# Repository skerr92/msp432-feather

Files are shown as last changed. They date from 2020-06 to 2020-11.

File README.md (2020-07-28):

# msp432-feather

Welcome to the public repository for my MSP432P401R feather board design. There are just a few things that should be considered when working with this design. 

<image src="images/Screen Shot 2020-07-28 at 7.55.07 PM.png">
  
# Update (07-28-2020): Fixed issues with bad footprint for FT232RL chip

There was a connection and foodprint issue with the FT232RL chip which need to be replaced. That is reflected in the current board and schematic files.

In addition to this, 4 JTAG header pins are also added to allow programming from a MSP432P401R development board.

# Update (07-16-2020)

The schematic and board files were fixed related to the floating TEST pin on the FT232RL IC.

# Update (07-11-2020): If you choose to manufacture the current board uploaded read this first (fixed):

The old schematic is working to be updated following an issue with the FT232RL USB to UART chip. This is easy to overcome when assembling the current board, simply bridge pins 25 and 26 on the board. This ensures that pin 25 (TEST) is tied to pin 26 (GND). According to the FT232R datasheet, the chip won't be recognized because the test pin is floating. This will be corrected in the next revision.

# Get started today

You can get started by ordering the board from OshPark --> <a href="https://oshpark.com/shared_projects/jjmrRj4x">MSP432 Boards on OshPark</a>

# 1

The design is open for revision. If you have experience with PCB design and would like to contribue, I encourage you to do so! Simply create a fork of the repository and you're good to go!

If you are new to PCB design and want to play around with the files, you can do that to! Just download autodesk eagle through autodesk fusion and you can get started.

# 2

The BOM and board files are included for convenience if you so chose to build out this board. I am in the midst of testing the current design so I haven't worked out all the flaws that might be associate with this PCB. 

I should be done with the first board by the end of August, and I'll update the board files, schematic, and the lot as necessary.

# final thoughts

This board is the second board I have been working on and adding the the open source community. With hard work, I hope that this board can be successfully submitted the the Open Hardware Association as a means to help others who want to develop with the MSP432, can do so with the additional support of the Adafruit feather wings and other add-on boards.

If you have any questions, you can open up an issue in the <a href="https://github.com/skerr92/msp432-feather/issues">Issues</a> tab of this repository!

Please check the <a href="https://github.com/skerr92/msp432-feather/tree/master/technical%20documentation">Technical Documentation</a> for additional resources for working with the MSP432P4xxx microcontroller.

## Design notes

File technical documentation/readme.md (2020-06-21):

# Getting started

Please see the data sheet for information on the feather board and associated pin out.

In addition to the technical document, please refer to the MSP432P401R bootloader uploading instructions from Texas Instruments that can be found below.

<a href="https://www.ti.com/lit/ug/slau622j/slau622j.pdf?ts=1592760815341">MSP432 bootloader instructions</a>

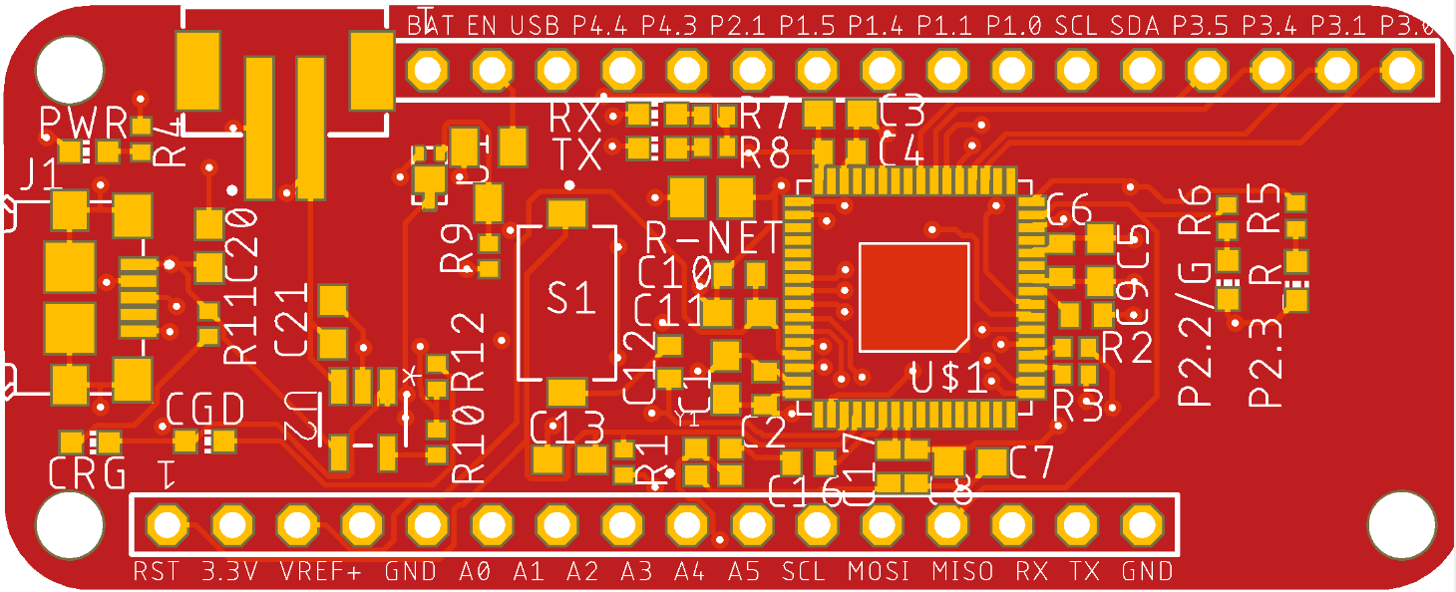
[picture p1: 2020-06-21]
images/Screen Shot 2020-06-17 at 4.03.39 PM.png

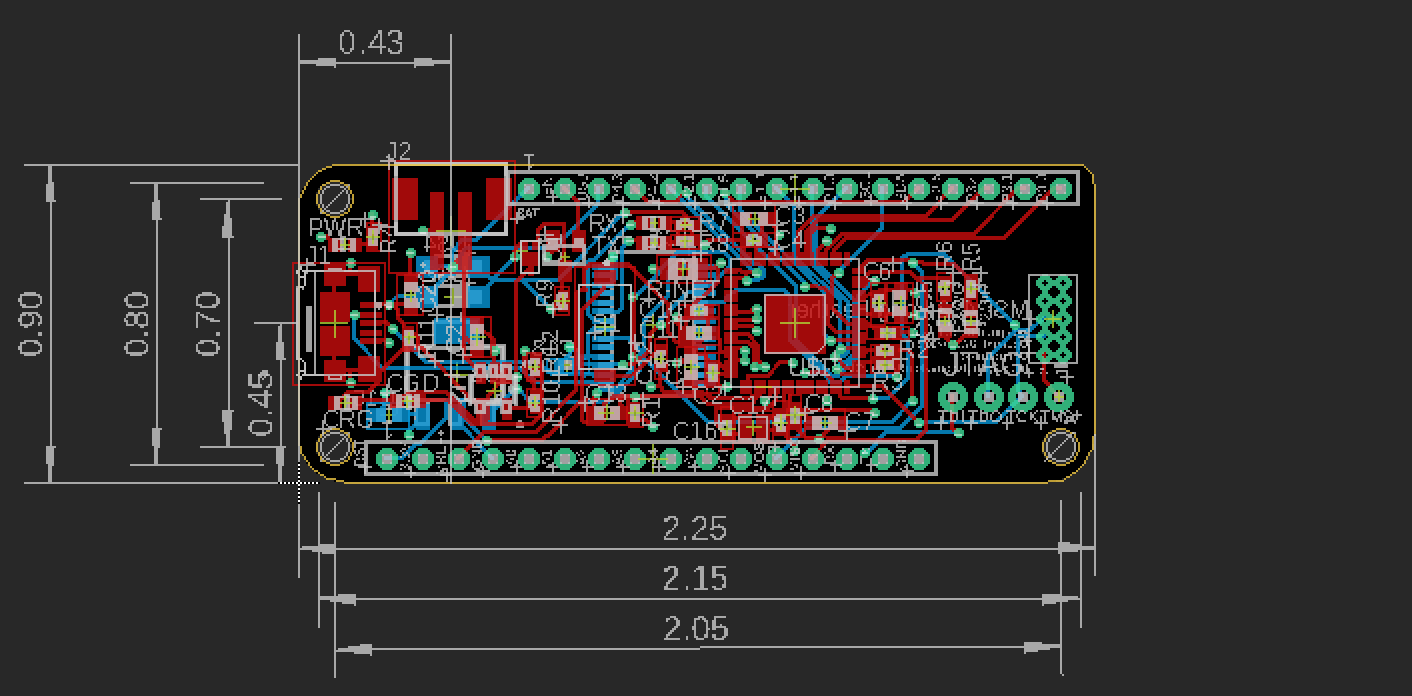
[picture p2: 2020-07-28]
images/Screen Shot 2020-07-28 at 7.55.07 PM.png

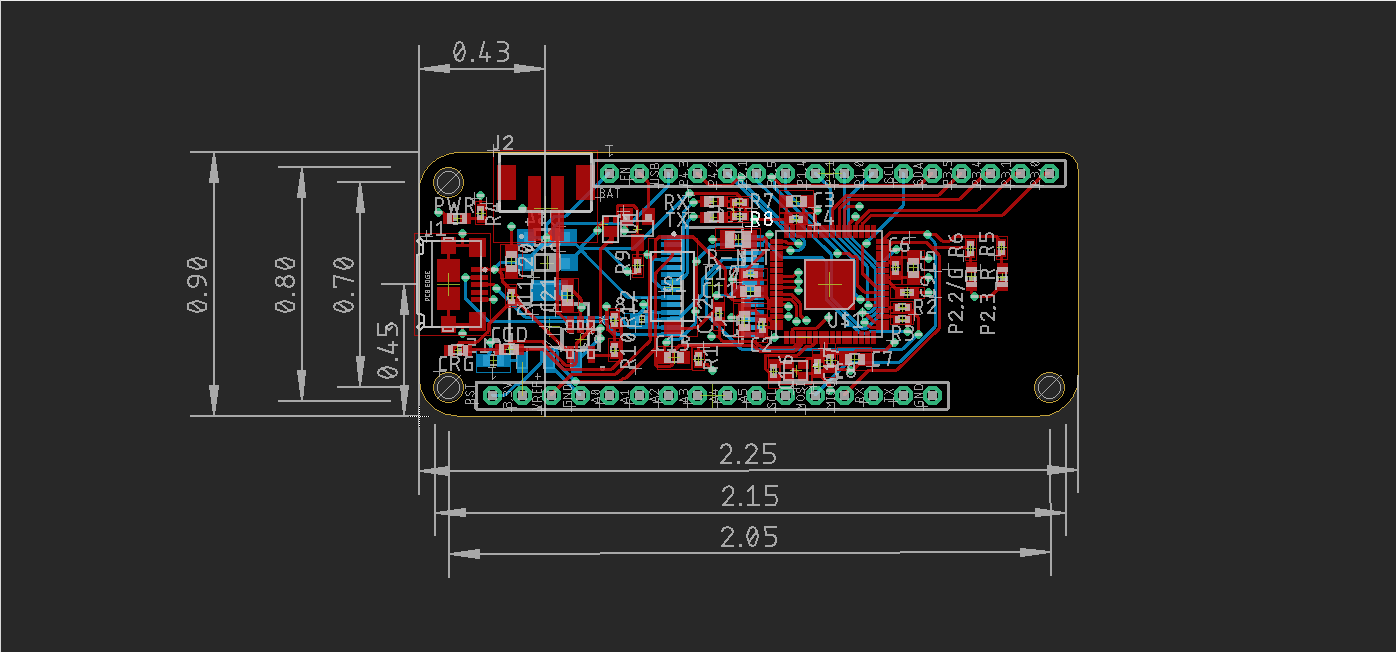
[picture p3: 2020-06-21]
images/Screen Shot 2020-06-21 at 1.09.43 PM.png

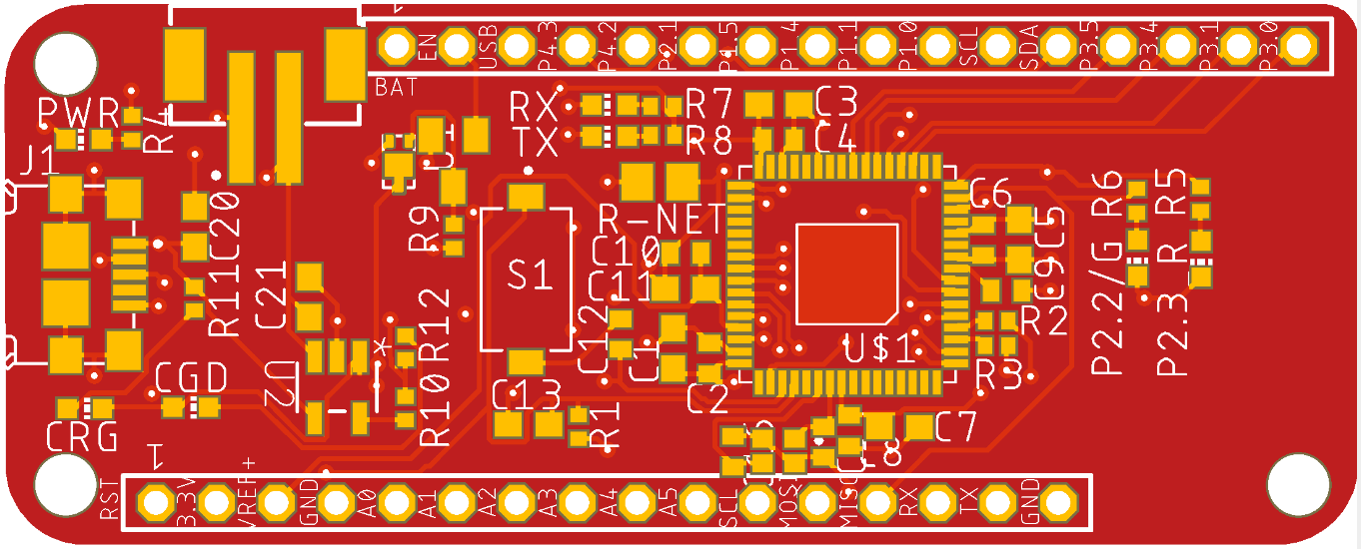
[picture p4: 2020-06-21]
images/Screen Shot 2020-06-17 at 5.07.13 PM.png

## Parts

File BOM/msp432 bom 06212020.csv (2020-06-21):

Index | Quantity | Part Number | Manufacturer Part Number | Description | Customer Reference | Available | Backorder | Unit Price | Extended Price USD
1 | 1 | 768-1007-1-ND | FT232RL-REEL | IC USB FS SERIAL UART 28-SSOP |  | 1 | 0 | 4.50000 | 4.50
2 | 1 | 455-1734-1-ND | B2B-PH-SM4-TB(LF)(SN) | CONN HEADER SMD 2POS 2MM |  | 1 | 0 | 0.55000 | 0.55
3 | 1 | 296-45565-1-ND | MSP432P401RIRGCR | IC MCU 32BIT 256KB FLASH 64VQFN |  | 1 | 0 | 6.66000 | 6.66
4 | 2 | MBR0520LT1GOSCT-ND | MBR0520LT1G | DIODE SCHOTTKY 20V 500MA SOD123 |  | 2 | 0 | 0.29000 | 0.58
5 | 1 | DMG3415UFY4Q-7DICT-ND | DMG3415UFY4Q-7 | MOSFET P-CH 16V 2.5A X2-DFN2015 |  | 1 | 0 | 0.51000 | 0.51
6 | 1 | BSS138CT-ND | BSS138 | MOSFET N-CH 50V 220MA SOT-23 |  | 1 | 0 | 0.26000 | 0.26
7 | 1 | MIC5239-3.3YS-CT-ND | MIC5239-3.3YS-TR | IC REG LINEAR 3.3V 500MA SOT223 |  | 1 | 0 | 2.66000 | 2.66
8 | 2 | 511-1494-1-ND | TCM0J106M8R | CAP TANT 10UF 20% 6.3V 0603 |  | 2 | 0 | 0.62000 | 1.24
9 | 1 | 445-8022-1-ND | C1005X5R1A335M050BC | CAP CER 3.3UF 10V X5R 0402 |  | 1 | 0 | 0.49000 | 0.49
10 | 2 | 399-7775-1-ND | C0402C220K5GACTU | CAP CER 22PF 50V C0G/NP0 0402 |  | 2 | 0 | 0.10000 | 0.20
11 | 10 | 1276-1004-1-ND | CL05F104ZO5NNNC | CAP CER 0.1UF 16V Y5V 0402 |  | 10 | 0 | 0.02000 | 0.20
12 | 1 | 399-9948-1-ND | C0402C112J5GAC7867 | CAP CER 1100PF 50V C0G/NP0 0402 |  | 1 | 0 | 0.54000 | 0.54
13 | 1 | 490-1316-1-ND | GRM155R71A473KA01D | CAP CER 0.047UF 10V X7R 0402 |  | 1 | 0 | 0.10000 | 0.10
14 | 5 | 718-2358-1-ND | TMCJ0J475MTRF | CAP TANT 4.7UF 20% 6.3V 0603 |  | 5 | 0 | 0.39000 | 1.95
15 | 2 | 311-220LRCT-ND | RC0402FR-07220RL | RES SMD 220 OHM 1% 1/16W 0402 |  | 2 | 0 | 0.10000 | 0.20
16 | 1 | RMCF0805ZT0R00CT-ND | RMCF0805ZT0R00 | RES 0 OHM JUMPER 1/8W 0805 |  | 1 | 0 | 0.10000 | 0.10
17 | 3 | A130045CT-ND | CRGCQ0402J330R | CRGCQ 0402 330R 5% |  | 3 | 0 | 0.10000 | 0.30
18 | 2 | A130046CT-ND | CRGCQ0402J470R | CRGCQ 0402 470R 5% |  | 2 | 0 | 0.10000 | 0.20
19 | 2 | P1.0KJCT-ND | ERJ-2GEJ102X | RES SMD 1K OHM 5% 1/10W 0402 |  | 2 | 0 | 0.10000 | 0.20
20 | 1 | A130375CT-ND | CRGP0402F47K | CRGP 0402 47K 1% |  | 1 | 0 | 0.10000 | 0.10
21 | 1 | 311-100KLRCT-ND | RC0402FR-07100KL | RES SMD 100K OHM 1% 1/16W 0402 |  | 1 | 0 | 0.10000 | 0.10
22 | 1 | P2.20KLCT-ND | ERJ-2RKF2201X | RES SMD 2.2K OHM 1% 1/10W 0402 |  | 1 | 0 | 0.10000 | 0.10
23 | 3 | 732-4966-1-ND | 150060BS75000 | LED BLUE CLEAR 0603 SMD |  | 3 | 0 | 0.16000 | 0.48
24 | 2 | 350-2035-1-ND | 5988070107F | LED GREEN CLEAR 0603 SMD |  | 2 | 0 | 0.42000 | 0.84
25 | 2 | 732-4978-1-ND | 150060RS75000 | LED RED CLEAR 0603 SMD |  | 2 | 0 | 0.14000 | 0.28
26 | 1 | XC2668CT-ND | ECS-480-10-37-JTN-TR | CRYSTAL 48MHZ 10PF SMD |  | 1 | 0 | 0.66000 | 0.66
27 | 1 | 609-5379-1-ND | 10118192-0002LF | CONN RCPT USB2.0 MICRO B SMD R/A |  | 1 | 0 | 0.46000 | 0.46

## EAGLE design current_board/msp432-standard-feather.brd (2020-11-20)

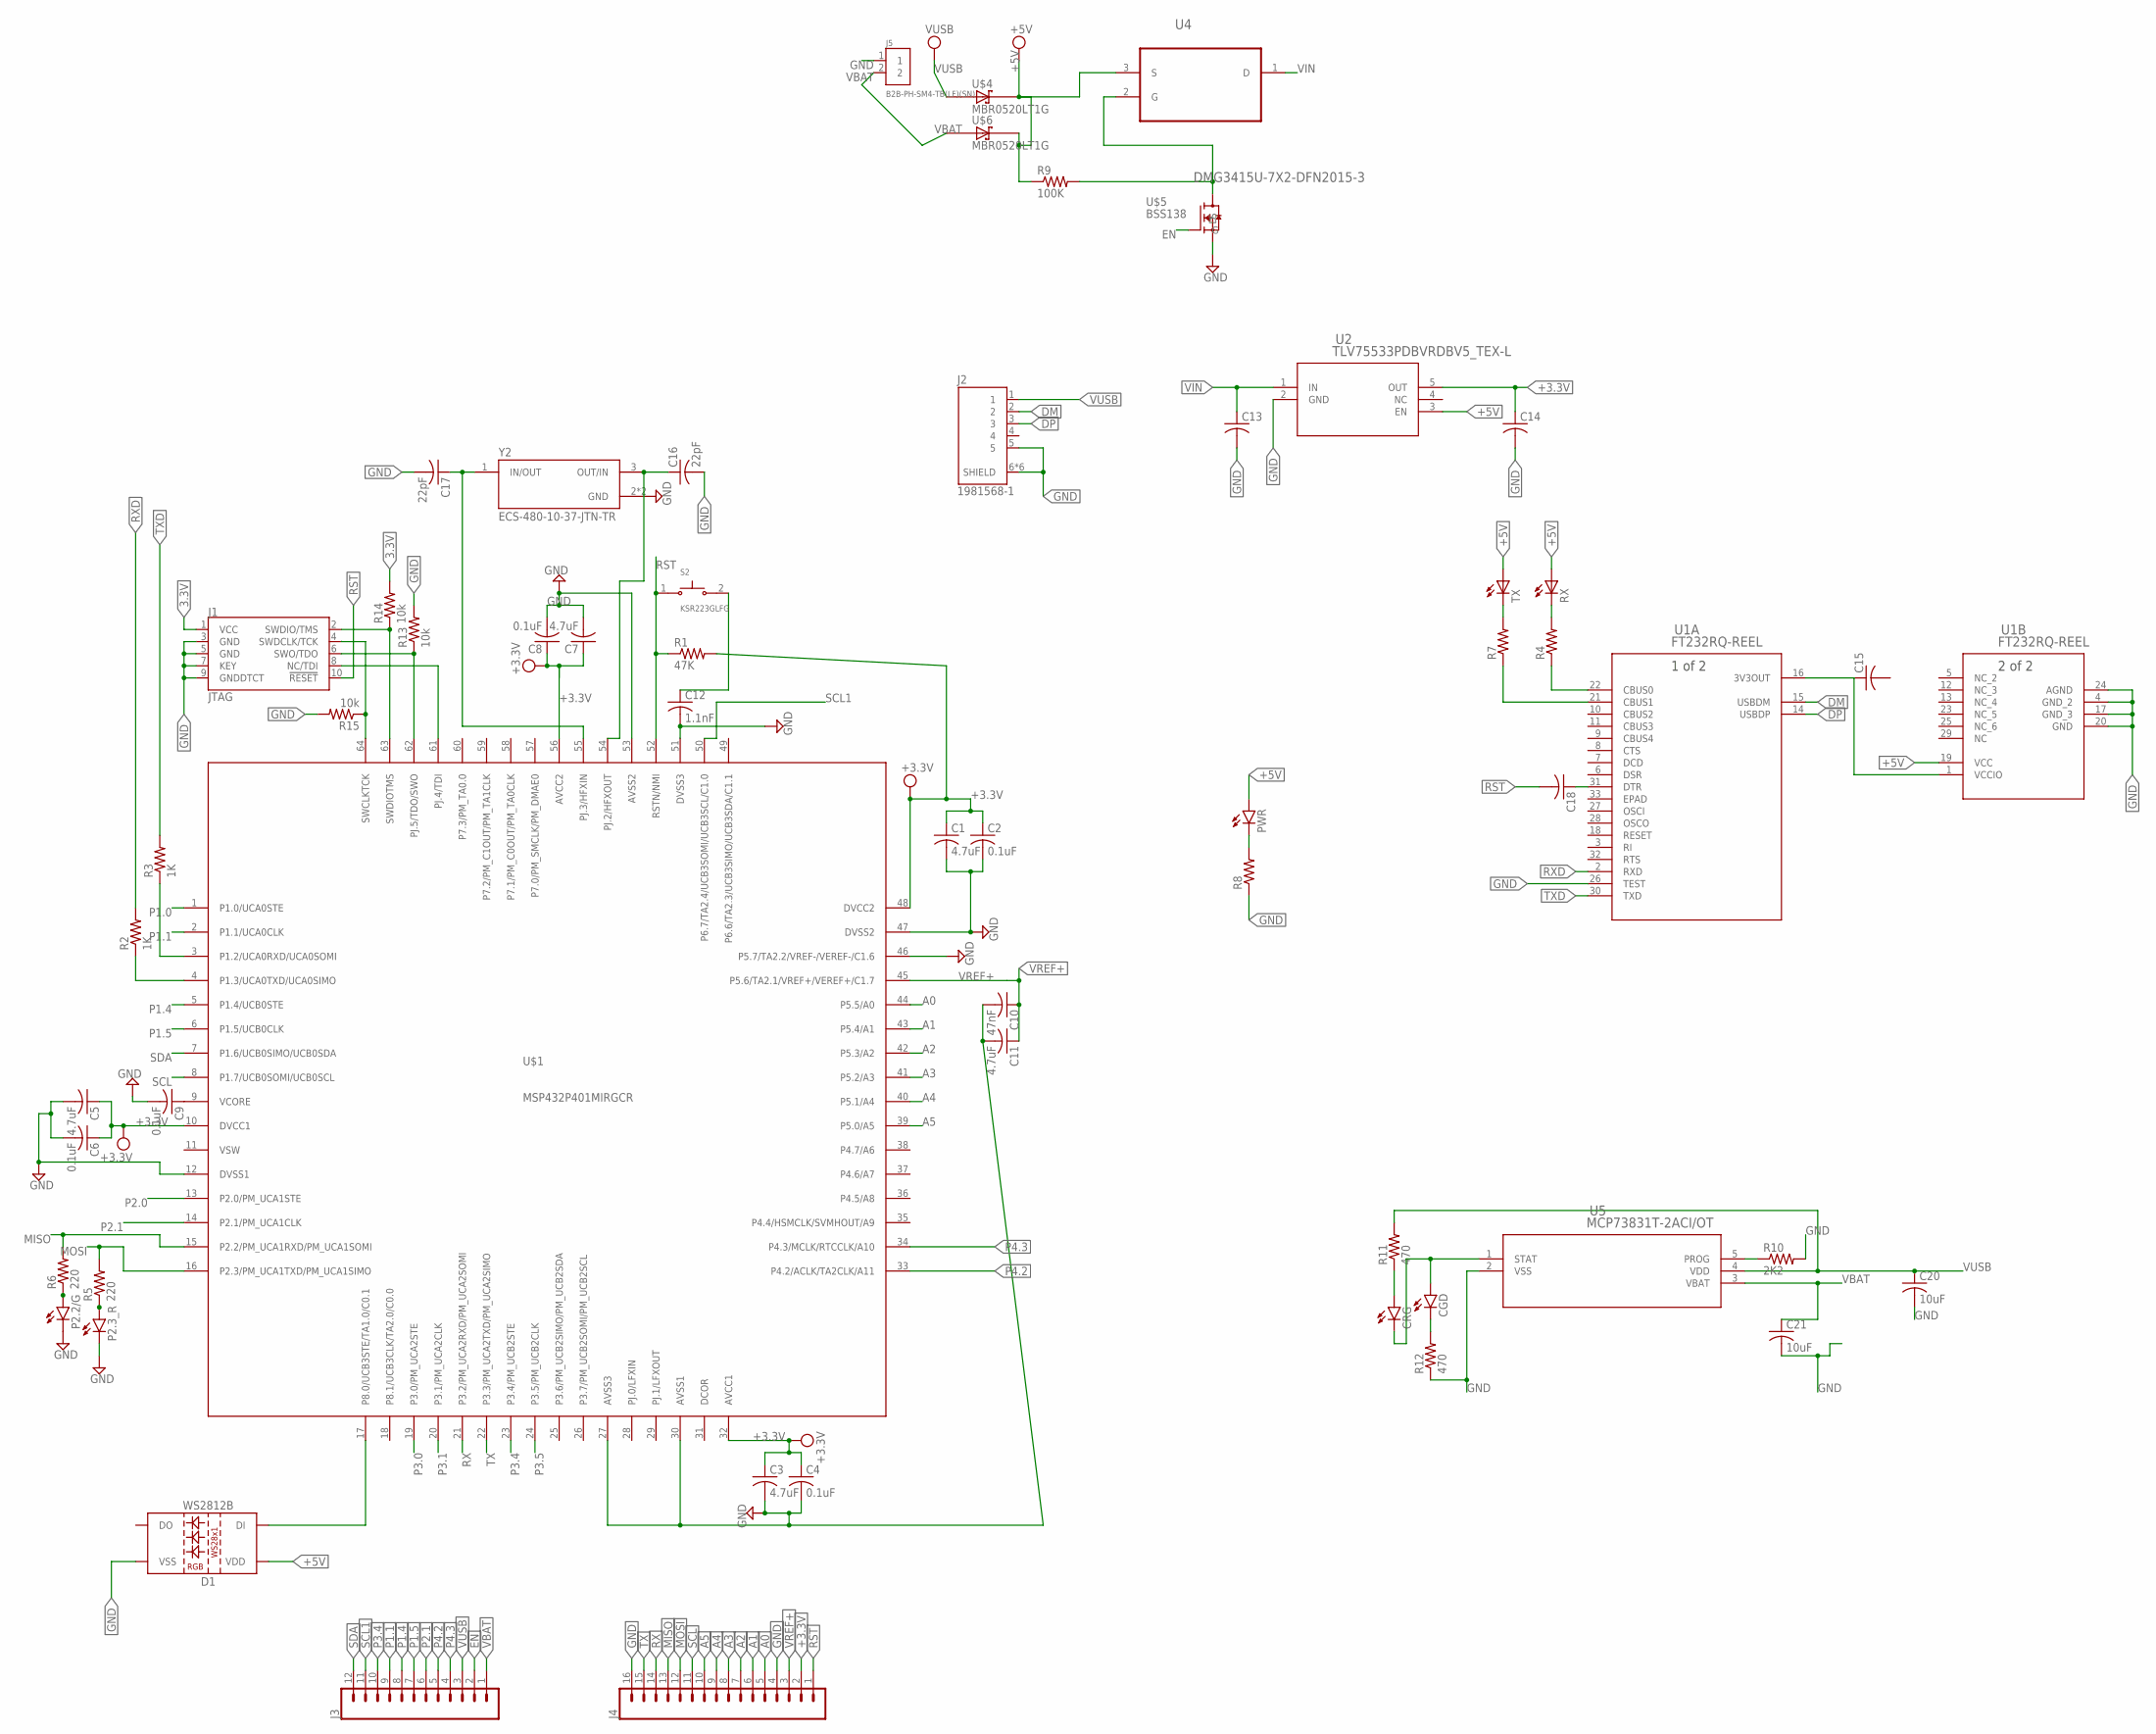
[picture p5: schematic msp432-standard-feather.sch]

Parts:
C1, C3, C5, C7, C11: 4.7uF; C0603
C2, C4, C6, C8, C9: 0.1uF; C0402
C10: 47nF; C0402
C12: 1.1nF; C0402
C13, C14, C15, C18: C-USC0402; C0402
C16, C17: 22pF; C0402
C20, C21: 10uF; C0603
CGD: LEDCHIP-LED0603; CHIP-LED0603
CRG: LEDCHIP-LED0603; CHIP-LED0603
D1: WS2812B
J1: JTAG; 2X5-SMD-1.27MM
J2: 1981568-1; TE_1981568-1
J3: CONN_12NO_SILK; 1X12_NO_SILK
J4: CONN_161X16_NO_SILK; 1X16_NO_SILK
J5: B2B-PH-SM4-TB(LF)(SN); JST_B2B-PH-SM4-TB(LF)(SN)
P2.2/G, P2.3_R: LEDCHIP-LED0603; CHIP-LED0603
PWR: LEDCHIP-LED0603; CHIP-LED0603
R1: 47K; R0402
R2, R3: 1K; R0402
R4, R7, R8: R-US_R0402; R0402
R5, R6: 220; R0402
R9: 100K; R0402
R10: 2K2; R0402
R11, R12: 470; R0402
R13, R14, R15: 10k; R0402
RX: LEDCHIP-LED0603; CHIP-LED0603
S2: KSR223GLFG; SW_KSR223GLFG
TX: LEDCHIP-LED0603; CHIP-LED0603
U1: FT232RQ-REEL; FT232RQ-REEL_FTD
U2: TLV75533PDBVRDBV5_TEX-L; DBV5_TEX-L
U4: DMG3415U-7X2-DFN2015-3; X2-DFN2015-3
U5: MCP73831T-2ACI/OT; SOT-23-5_MC
U$1: MSP432P401MIRGCR; MSP432_QFN_64
U$4, U$6: MBR0520LT1G; SOD3716X117(SOD-123)
U$5: BSS138
Y2: ECS-480-10-37-JTN-TR; XTAL_ECS-480-10-37-JTN-TR

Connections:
3.3V: J1.1 (VCC), R14.2
+3.3V: C1.1, C2.1, C3.1, C4.1, C5.1, C6.1, C7.1, C8.1, C14.1, J4.2, R1.2, U2.5 (OUT), U$1.10 (DVCC1), U$1.32 (AVCC1), U$1.48 (DVCC2), U$1.56 (AVCC2)
+5V: D1.1 (VDD), PWR.A, R9.1, RX.A, TX.A, U1.19 (VCC), U2.3 (EN), U4.3 (S), U$4.1 (C), U$6.1 (C)
A0: J4.5, U$1.44 (P5.5/A0)
A1: J4.6, U$1.43 (P5.4/A1)
A2: J4.7, U$1.42 (P5.3/A2)
A3: J4.8, U$1.41 (P5.2/A3)
A4: J4.9, U$1.40 (P5.1/A4)
A5: J4.10, U$1.39 (P5.0/A5)
DM: J2.2, U1.15 (USBDM)
DP: J2.3, U1.14 (USBDP)
EN: J3.2, U$5.G
GND: C1.2, C2.2, C3.2, C4.2, C5.2, C6.2, C7.2, C8.2, C9.2, C10.2, C11.2, C12.2, C13.2, C14.2, C16.2, C17.2, C20.2, C21.2, D1.3 (VSS), J1.3 (GND), J1.5 (GND), J1.7 (KEY), J1.9 (GNDDTCT), J2.5, J2.6 (SHIELD), J2.7 (SHIELD), J2.8 (SHIELD), J2.9 (SHIELD), J2.10 (SHIELD), J2.11 (SHIELD), J4.4, J4.16, J5.1, P2.2/G.C, P2.3_R.C, R8.1, R10.2, R12.1, R13.2, R15.2, U1.4 (GND_2), U1.17 (GND_3), U1.20 (GND), U1.24 (AGND), U1.26 (TEST), U2.2 (GND), U5.2 (VSS), U$1.12 (DVSS1), U$1.27 (AVSS3), U$1.30 (AVSS1), U$1.46 (P5.7/TA2.2/VREF-/VEREF-/C1.6), U$1.47 (DVSS2), U$1.51 (DVSS3), U$1.53 (AVSS2), U$5.S, Y2.2 (GND), Y2.4 (GND)
MISO: J4.13, R6.2, U$1.15 (P2.2/PM_UCA1RXD/PM_UCA1SOMI)
MOSI: J4.12, R5.2, U$1.16 (P2.3/PM_UCA1TXD/PM_UCA1SIMO)
unnamed: C9.1, U$1.9 (VCORE)
unnamed: R10.1, U5.5 (PROG)
unnamed: C15.1, U1.1 (VCCIO), U1.16 (3V3OUT)
unnamed: C18.1, U1.31 (DTR)
unnamed: R7.1, U1.21 (CBUS1)
unnamed: R4.1, U1.22 (CBUS0)
unnamed: R4.2, RX.C
unnamed: R7.2, TX.C
unnamed: J1.4 (SWDCLK/TCK), R15.1, U$1.64 (SWCLKTCK)
unnamed: C12.1, S2.2
unnamed: J1.2 (SWDIO/TMS), R14.1, U$1.63 (SWDIOTMS)
unnamed: PWR.C, R8.2
unnamed: P2.2/G.A, R6.1
unnamed: R2.1, U$1.4 (P1.3/UCA0TXD/UCA0SIMO)
unnamed: R3.1, U$1.3 (P1.2/UCA0RXD/UCA0SOMI)
unnamed: J1.6 (SWO/TDO), R13.1, U$1.62 (PJ.5/TDO/SWO)
unnamed: R9.2, U4.2 (G), U$5.D
unnamed: CGD.A, CRG.C, U5.1 (STAT)
unnamed: J1.8 (NC/TDI), U$1.61 (PJ.4/TDI)
unnamed: D1.4 (DI), U$1.17 (P8.0/UCB3STE/TA1.0/C0.1)
unnamed: CGD.C, R12.2
unnamed: CRG.A, R11.1
unnamed: P2.3_R.A, R5.1
unnamed: C16.1, U$1.54 (PJ.2/HFXOUT), Y2.3 (OUT/IN)
unnamed: C17.1, U$1.55 (PJ.3/HFXIN), Y2.1 (IN/OUT)
P1.0: U$1.1 (P1.0/UCA0STE)
P1.1: J3.9, U$1.2 (P1.1/UCA0CLK)
P1.4: J3.8, U$1.5 (P1.4/UCB0STE)
P1.5: J3.7, U$1.6 (P1.5/UCB0CLK)
P2.0: U$1.13 (P2.0/PM_UCA1STE)
P2.1: J3.6, U$1.14 (P2.1/PM_UCA1CLK)
P3.0: U$1.19 (P3.0/PM_UCA2STE)
P3.1: U$1.20 (P3.1/PM_UCA2CLK)
P3.4: J3.10, U$1.23 (P3.4/PM_UCB2STE)
P3.5: U$1.24 (P3.5/PM_UCB2CLK)
P4.2: J3.5, U$1.33 (P4.2/ACLK/TA2CLK/A11)
P4.3: J3.4, U$1.34 (P4.3/MCLK/RTCCLK/A10)
RST: C18.2, J1.10 (!RESET), J4.1, R1.1, S2.1, U$1.52 (RSTN/NMI)
RX: J4.14, U$1.21 (P3.2/PM_UCA2RXD/PM_UCA2SOMI)
RXD: R2.2, U1.2 (RXD)
SCL: J4.11, U$1.8 (P1.7/UCB0SOMI/UCB0SCL)
SCL1: J3.11, U$1.50 (P6.7/TA2.4/UCB3SOMI/UCB3SCL/C1.0)
SDA: J3.12, U$1.7 (P1.6/UCB0SIMO/UCB0SDA)
TX: J4.15, U$1.22 (P3.3/PM_UCA2TXD/PM_UCA2SIMO)
TXD: R3.2, U1.30 (TXD)
VBAT: C21.1, J3.1, J5.2, U5.3 (VBAT), U$6.2 (A)
VIN: C13.1, U2.1 (IN), U4.1 (D)
VREF+: C10.1, C11.1, J4.3, U$1.45 (P5.6/TA2.1/VREF+/VEREF+/C1.7)
VUSB: C20.1, J2.1, J3.3, R11.2, U5.4 (VDD), U$4.2 (A)

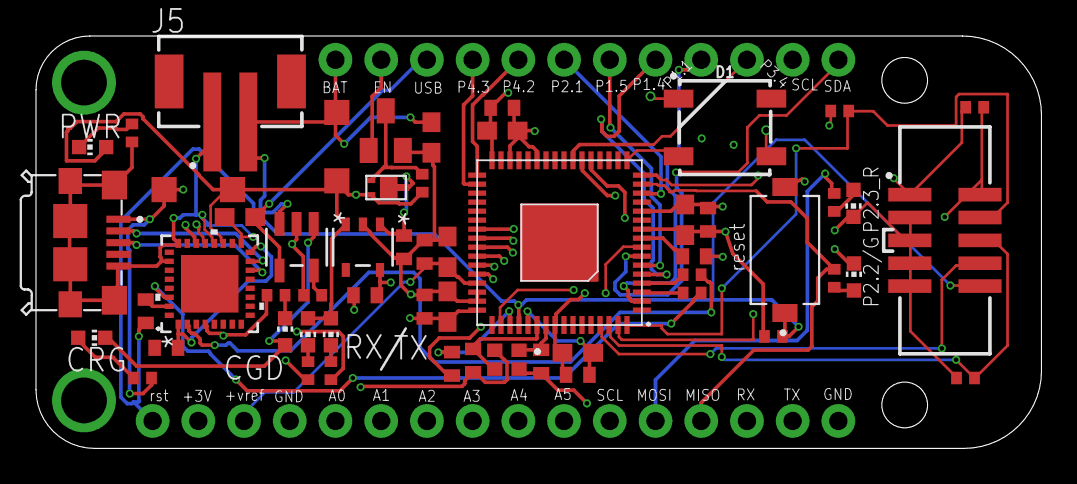
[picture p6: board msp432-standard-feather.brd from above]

Board: 4 copper layers, 55.9 x 22.9 mm, 58 parts (0 on the bottom side), 59 nets.

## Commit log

2020-06-21 Add files via upload
    bill of materials that can be uploaded to DigiKey
    [msp432 bom 06212020.csv]
2020-07-13 Update README.md
    updating information about TEST pin on FT232RL USB to UART chip on board.
2020-07-16 updated board file
    Fixed issue with floating TEST pin on FT232RL IC
    [msp432 feather board.brd]
2020-07-16 updating schematic
    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
    [msp432 feather board.sch]
2020-07-16 updating readme
    updated readme to reflect changes to the board and schematic files
2020-07-28 Add files via upload
    fixing JTAG and adding ARM 10pin JTAG connector
    [msp432 feather board.brd]
2020-07-28 Add files via upload
    fixing JTAG stuff and adding 10 pin ARM JTAG to schematic and board.
    [msp432 feather board.sch]
2020-07-29 Add files via upload
    wiring issues with the USB interface.
    [msp432 feather board.brd]
2020-07-29 Add files via upload
    fixed wiring issues on the schematic for the usb interface
    [msp432 feather board.sch]
2020-11-20 Add files via upload
    adding corrected feather
    [msp432-standard-feather.brd]
2020-11-20 Delete msp432 feather board.brd
    old design doesn't work
    [msp432 feather board.brd]
2020-11-20 Add files via upload
    updated schematic
    [msp432-standard-feather.sch]
2020-11-20 Delete msp432 feather board.sch
    removing old schematic
    [msp432 feather board.sch]

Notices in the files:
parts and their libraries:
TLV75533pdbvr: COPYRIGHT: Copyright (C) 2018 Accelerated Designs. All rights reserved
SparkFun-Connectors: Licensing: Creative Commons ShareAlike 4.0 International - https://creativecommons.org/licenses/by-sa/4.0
